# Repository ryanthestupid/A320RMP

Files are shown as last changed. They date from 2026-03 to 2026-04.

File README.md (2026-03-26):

# A320RMP
## A320 Radio Management Panel
_Made for MSFS2020, MobiFlight, RP2040, and the FlyByWire A32NX_

### What is this?
The A320RMP is a small desktop radio management panel for use with Microsoft Flight Simulator and MobiFlight, and is based off the Raspberry Pi RP2040 platform.

### Why was this made?
While flying on VATSIM with MSFS2020, I realized it was very difficult to switch frequencies through the mouse and scroll wheel in the FlyByWire A32NX. So, here is my version of the A320 RMP.

## Firmware
This RMP uses [MobiFlight](https://mobiflight.com) for its firmware and programming with a RP2040.<br>
MobiFlight Firmware and Project Files are in `mobiflight/` (`mfmc` and `mfproj`)<br>
**NOTE: RP2350/Pi Pico 2 will NOT work with MobiFlight. Only the RP2040 or Pi Pico 1 is compatible.**

## Links
Project Website (WIP) - https://ko6lvm.org/projects/a320rmp<br>
Hack Club Stasis Project - https://stasis.hackclub.com/dashboard/discover/cmmssstp8007o01myxmtd4il3

## Pictures
### Project Image
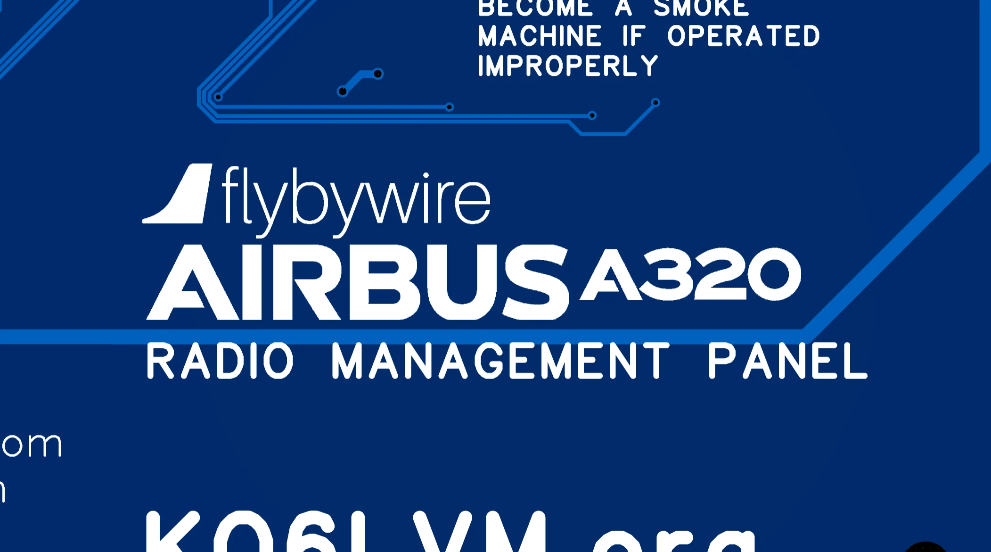
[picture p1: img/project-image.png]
Project Image
<br>
### Schematic
`img/schematic.png`<br>Schematic
### PCB
`img/pcb.png` - `pcb/A320RMPv1FinalGerber.zip`<br>PCB
### CAD / Models
#### Knob
`img/knob.png` - `cad/knob.step`<br>Knob<br>
#### Case
`img/case.png` - `cad/case.step`<br>Case<br>
#### Lid
`img/lid.png` - `cad/lid.step`<br>Lid<br>
#### Buttons
`img/button.png` - `cad/button.step`<br>Button<br>
### Final Render
`img/final1.png`<br>Final 1<br>
`img/final2.png`<br>Final 2<br>
`img/final3.png`<br>Final 3<br>

## BoM (General)
_Stasis BoM_ (`bom-stasis.csv`) _includes shipping, tax, fees, and required tools._<br>
_Below: General BoM_ (`bom-general.csv`)
| Name | Purpose | Quantity | Total Cost (USD) | Link | Distributor |
| :--- | :--- | :--- | :--- | :--- | :--- |
| Waveshare RP2040+ | Pico USB-C | 1 | 14.99 | [Link](https://www.amazon.com/RP2040-Plus-High-Performance-Microcontroller-Compatible-Pre-soldered/dp/B09KZFJTV9) | Amazon |
| SMD Stencil | Soldering | 1 | 7.11 | [Link](https://jlcpcb.com) | JLCPCB |
| PCB | 5 minimum | 5 | 9.00 | [Link](https://jlcpcb.com) | JLCPCB |
| Flux 30g | Paste | 1 | 9.99 | [Link](https://www.amazon.com/gp/product/B0D3H8NZLP) | Amazon |
| Solder Paste 30g | Sn63/Pb37 | 1 | 12.99 | [Link](https://www.amazon.com/gp/product/B0BH4HRWGX) | Amazon |
| Female Header Pins | Header C7499336 | 5 | 1.20 | [Link](https://www.lcsc.com/product-detail/C7499336.html) | LCSC |
| SPST Switch | Switch C1788492, THT | 2 | 1.26 | [Link](https://www.lcsc.com/product-detail/C1788492.html) | LCSC |
| Multiplexer IC | Multiplexer C6525 | 2 | 1.42 | [Link](https://www.lcsc.com/product-detail/C6525.html) | LCSC |
| 7seg CT IC | 7seg Controller IC C6705351 | 4 | 6.28 | [Link](https://www.lcsc.com/product-detail/C6705351.html) | LCSC |
| Logic Level IC | TI Logic Lvl C155176, 3.3V to 5V | 2 | 0.66 | [Link](https://www.lcsc.com/product-detail/C155176.html) | LCSC |
| Green L0603 | LED C19273151, min 100 | 100 | 0.60 | [Link](https://www.lcsc.com/product-detail/C19273151.html) | LCSC |
| Rotary Encoder | Rot Enc C470754, THT | 3 | 6.24 | [Link](https://www.lcsc.com/product-detail/C470754.html) | LCSC |
| 22Kohm R0603 | Resistor C2907015, min 100 | 100 | 0.10 | [Link](https://www.lcsc.com/product-detail/C2907015.html) | LCSC |
| 220ohm R0603 | Resistor C22962, min 100 | 100 | 0.13 | [Link](https://www.lcsc.com/product-detail/C22962.html) | LCSC |
| 6digit 7segment Display | Display C47471 | 3 | 5.20 | [Link](https://www.lcsc.com/product-detail/C47471.html) | LCSC |
| 6x6mm Button | Button C49234152, min 20 | 20 | 0.61 | [Link](https://www.lcsc.com/product-detail/C49234152.html) | LCSC |
| 10uF C0603 | Capacitor C1591, min 20 | 20 | 0.35 | [Link](https://www.lcsc.com/product-detail/C96446.html) | LCSC |
| 0.1uF C0603 | Capacitor C1591, min 100 | 100 | 0.28 | [Link](https://www.lcsc.com/product-detail/C1591.html) | LCSC |
_plus Applicable Tax, Fees, Shipping, and Tools_

## A320RMP wouldn't be possible without:
* VATSIM, https://vatsim.net
* MobiFlight, https://mobiflight.com
* FlyByWire Simulations, https://flybywiresim.com
* Hack Club, https://hackclub.com
* Stasis, https://stasis.hackclub.com

### A shoutout to:
* Oakland vARTCC, https://oakartcc.org

### And most importantly,
* @witherman3000, https://witherman3000.com

<br>Thanks for looking through my project!<br>
`5NN TNX FER QSO DE KO6LVM SK CL`

https://KO6LVM.org

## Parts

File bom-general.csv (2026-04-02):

Name | Purpose | Quantity | Total Cost (USD) | Link | Distributor
Waveshare RP2040+ | Pico USB-C | 1 | 14.99 | https://www.amazon.com/RP2040-Plus-High-Performance-Microcontroller-Compatible-Pre-soldered/dp/B09KZFJTV9 | Amazon
SMD Stencil | Soldering | 1 | 7.11 | https://jlcpcb.com | JLCPCB
PCB | 5 minimum | 5 | 9.00 | https://jlcpcb.com | JLCPCB
Flux 30g | Paste | 1 | 9.99 | https://www.amazon.com/gp/product/B0D3H8NZLP | Amazon
Solder Paste 30g | Sn63/Pb37 | 1 | 12.99 | https://www.amazon.com/gp/product/B0BH4HRWGX | Amazon
Female Header Pins | Header C7499336 | 5 | 1.20 | https://www.lcsc.com/product-detail/C7499336.html | LCSC
SPST Switch | Switch C1788492, THT | 2 | 1.26 | https://www.lcsc.com/product-detail/C1788492.html | LCSC
Multiplexer IC | Multiplexer C6525 | 2 | 1.42 | https://www.lcsc.com/product-detail/C6525.html | LCSC
7seg CT IC | 7seg Controller IC C6705351 | 4 | 6.28 | https://www.lcsc.com/product-detail/C6705351.html | LCSC
Logic Level IC | TI Logic Lvl C155176, 3.3V to 5V | 2 | 0.66 | https://www.lcsc.com/product-detail/C155176.html | LCSC
Green L0603 | LED C19273151, min 100 | 100 | 0.60 | https://www.lcsc.com/product-detail/C19273151.html | LCSC
Rotary Encoder | Rot Enc C470754, THT | 3 | 6.24 | https://www.lcsc.com/product-detail/C470754.html | LCSC
22Kohm R0603 | Resistor C2907015, min 100 | 100 | 0.10 | https://www.lcsc.com/product-detail/C2907015.html | LCSC
220ohm R0603 | Resistor C22962, min 100 | 100 | 0.13 | https://www.lcsc.com/product-detail/C22962.html | LCSC
6digit 7segment Display | Display C47471 | 3 | 5.20 | https://www.lcsc.com/product-detail/C47471.html | LCSC
6x6mm Button | Button C49234152, min 20 | 20 | 0.61 | https://www.lcsc.com/product-detail/C49234152.html | LCSC
10uF C0603 | Capacitor C96446, min 20 | 20 | 0.35 | https://www.lcsc.com/product-detail/C96446.html | LCSC
0.1uF C0603 | Capacitor C1591, min 100 | 100 | 0.28 | https://www.lcsc.com/product-detail/C1591.html | LCSC

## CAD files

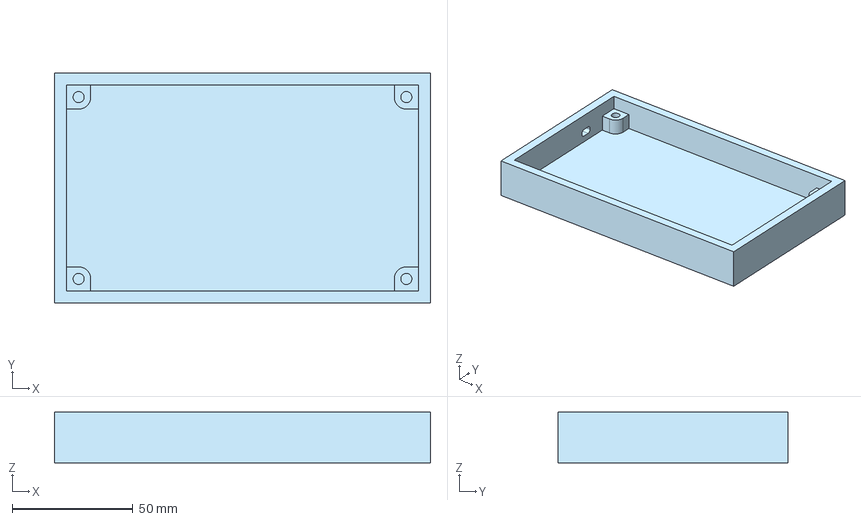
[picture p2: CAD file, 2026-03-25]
A320RMPCase.step
155.7 x 95.3 x 21.0 mm

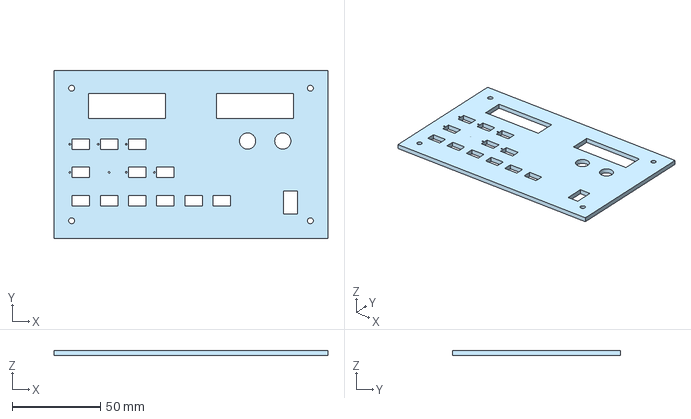
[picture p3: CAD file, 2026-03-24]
A320RMPLid.step
155.7 x 95.3 x 3.00 mm

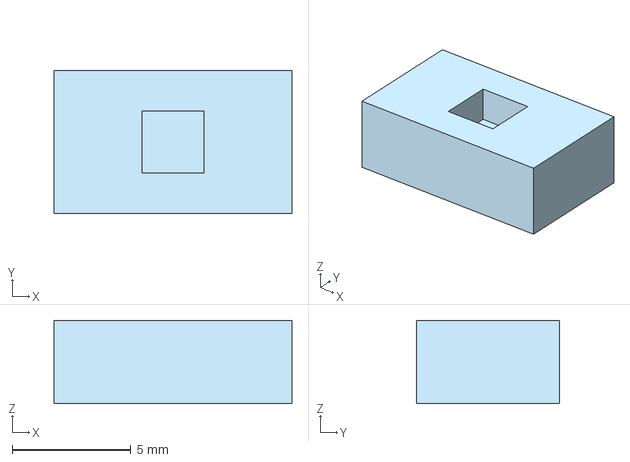
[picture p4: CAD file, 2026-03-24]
A320RMPButton.step
10.0 x 6.00 x 3.50 mm

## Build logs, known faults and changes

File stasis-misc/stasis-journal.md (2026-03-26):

<!--
  This journal is auto generated by Stasis.
-->

# 3/26/2026 2 AM - Everything Done!

_Time spent: 0.01666666666666667h_

1 min logged as I need to log *some* time for the journal.

Everything has been completed, as per the *Submission Guidelines*.



Checklist
* Originality - yes, this is my project.
* Shipped and complete:
* CAD assembly with all electronics and parts - Yes
* Firmware present - yes (mobiflight)
* Sanity checked - yes
* 3D Render - "render"-ish, but yes.
* BOM in CSV - Generic and Stasis, yes.
* PCB source files - Gerber, yes.
* Any other files - Mobiflight config files, etc, yes.
* STEP files for CAD files, yes. (`cad/`)
* Readable and organized into folders, yes.

Readme:
* Description - yes
* Sentences on why - yes
* Pictures - plenty, yes
* Screenshot with full model - yes
* PCB screenshot - yes
* Wiring diagrams - yes (schematic)
* BoM in table format - yes






# 3/25/2026 7 AM - README (In Stasis Copy)

_Time spent: 2h_

# Rest of completed Readme and BOM in Github
# A320RMP
## A320 Radio Management Panel
_Made for MSFS2020, MobiFlight, RP2040, and the FlyByWire A32NX_

### What is this?
The A320RMP is a small desktop radio management panel for use with Microsoft Flight Simulator and MobiFlight, and is based off the Raspberry Pi RP2040 platform.

### Why was this made?
While flying on VATSIM with MSFS2020, I realized it was very difficult to switch frequencies through the mouse and scroll wheel in the FlyByWire A32NX. So, here is my version of the A320 RMP.

## Pictures
### Schematic
`img/schematic.png`
A320RMPv1Schematic
https://stasis.hackclub-assets.com/images/1774469948065-c5vn6g.png
### PCB Only
`img/pcb.png`
A320RMPv1PCB2DTop
https://stasis.hackclub-assets.com/images/1774470086891-i2ej90.png
### CAD / Models
#### Knob
`img/knob.png`
`cad/knob.step`

https://stasis.hackclub-assets.com/images/1774470168708-qcuh1a.png
#### Case

https://stasis.hackclub-assets.com/images/1774470365832-sbevvn.png
#### Lid

https://stasis.hackclub-assets.com/images/1774470316983-m36m6g.png
#### Buttons

https://stasis.hackclub-assets.com/images/1774470339608-9jjzfl.png
### Final Render




## BoM
WIP - Check Stasis

## A320RMP wouldn't be possible without:
* VATSIM, https://vatsim.net
* FlyByWire Simulations, https://flybywiresim.com
* Oakland vARTCC, https://oakartcc.org
* Hack Club, https://hackclub.com
* Stasis, https://stasis.hackclub,com
### And most importantly,
* @witherman3000, https://witherman3000.com

Thanks for looking through my project!
`5NN THX FER RPRT DE KO6LVM SK CL`











# 3/25/2026 4 AM - Github, Readme, and Knob

_Time spent: 1.5h_

## Knob
Knob - made in Onshape, from encoder specs from LCSC


## Github
Uploaded:
* PCB STEP
* PCB Gerber
* Case STEP
* Lid STEP
* Button STEP
* Knob STEP
* Mobiflight MFMC
* Mobiflight MFPROJ
* https://github.com/ko6lvm/A320RMP

## README
WIP - on local disk. Will be uploaded ~26-27th.
Screenshot 2026-03-25 at 12.11.35 AM




# 3/25/2026 2 AM - MobiFlight Firmware

_Time spent: 2h_

* Firmware and project file uploaded to Github
* HF1/HF2/SEL/AM LEDs not configured due to those variables not present in A32NX MobiFlight presets
* Everything else programmed into MobiFlight
* Rotary encoder button as of now does not do anything











# 3/24/2026 9 PM - MobiFlight Pins

_Time spent: 2h_

## Multiplexer
### Data
| Name | IC Pin | Pico GP |
|---|---|---|
| S0 | 10 | GP0 |
| S1 | 11 | GP1 |
| S2 | 14 | GP2 |
| S3 | 13 | GP3 |
| C I/O | 1 | GP4 |
### Buttons
| Name | IC Pin |
|-----|-----|
| SW(N) | L(N) |
| i.e. S2 | L2 |

## Rotary Encoders
### SW13 (Left, MHz)
| Name | Pico GP | Purpose |
|-----|-----|-----|
| A | GP5 | Left |
| B | GP6 | Right |
| E | GP7 | Button |

### SW14 (Right, KHz)
| Name | Pico GP | Purpose |
|-----|-----|-----|
| A | GP8 | Left |
| B | GP9 | Right |
| E | GP10 | Button |

## LEDs
| Name | Pico GP | Purpose |
|-----|-----|-----|
| U3 | GP14 | VHF1 |
| U4 | GP15 | VHF2 |
| U5 | GP16 | VHF3 |
| U6 | GP17 | HF1 |
| U7 | GP18 | HF2 |
| U8 | GP19 | SEL |
| U9 | GP20 | AM |

## 7 Segments
_Uses MAX7219, 6 digits each._
_Data cascaded into U11 from U13 DOUT, only U13 recieves DIN from Pico/MobiFlight. All data is ran through Logic Level Shifter (Shifter pins used in place of MAX7219 pins)_
### U11-LED2 and U13-LED3
_UA in Name states Both U11 and U13_
| Name | Pico GP | Purpose |
|-----|-----|-----|
| U13 DIN | GP27_A2 | Data In |
| UA LOAD | GP22 | Load All |
| UA CLOCK | GP21 | Clock | 

## SPST On/Off
| Name | Pico GP |
|-----|-----|
| U15 | GP11 |

## Reference
_For the MAX7129 pins use the logic level shifter in pins instead_





## Mobiflight configs are on Github.




# 3/24/2026 3 AM - CAD

_Time spent: 3h_

## Lid



* 1mm OD circles for LEDs
* 16mm vert and horz spacing for buttons and LEDs
* Everything else done to PCB spec
* 5mm border

## Button



* 2.6mm button press-fit
* 6*10mm Button

## Case

* 4mm Bottom Spacing
* 9mm Top Spacing

## PCB
* DRC final run
* Silkscreen final
* Copper pour final rebuild
* Sanity checked

## Github Uploaded:
* Final PCB Gerber file ZIP
* Button STEP
* Lid STEP
* Case STEP
* PCB EasyEDA Pro STEP Export





# 3/22/2026 11 PM - CAD and Case

_Time spent: 1.25h_

## Dimensions
155.67mm * 95.3mm
(5mm wall)

* 7seg height: 9mm
* Pi Pico USB-C Clone w/ Headers: 4mm
* Female Headers: 4mm
* "Standoff" case height: 8.5mm
* Heat set insert OD: 5mm
* Heat set insert 3d print hole: 4.6mm
* All other components dimensions in their Datasheets


i.e. In this case, construction dual-point rect at 129.413x69.83mm and then a center-point-rect at its footprint

## Sanity checked!
## Case worked on
### Check Hackatime




# 3/22/2026 7 AM - PCB

_Time spent: 1h_

## PCB
* 2-layer design now
* 1mm power traces (yes, I don't need this much but it's fine)
* Made it 2-layer for cheaper JLCPCB costs
Screenshot 2026-03-22 at 12.30.13 AM

Screenshot 2026-03-22 at 12.30.29 AM




# 3/21/2026 1 AM - PCB

_Time spent: 2.5h_

## PCB
* Copper Pour for GND
* GND nets on Pico
* Component Data Routing
## BoM
* Stasis BoM populated with LCSC and Amazon parts
* JLCPCB will be added after quote








# 3/20/2026 3 AM - Parts Assignment

_Time spent: 0.75h_

# Parts BOM
## LCSC
* C = Capacitor
* R = Resistor
* L = LED
* B = Button
* IC = IC/Chip

_Note: Any item's quantity that's unreasonably high (i.e. 100 capacitors) is due to the minimum purchase count in LCSC. However, these are so cheap that 100 vs 4 won't really make a difference, as it is the matter of cents._
| Part | LCSC P# | Qty | Cost (Per)| Total |
|---|---|---|---|---|
| 0.1uF C0603 | C1591 | 100 | $0.0028 | $0.28 |
| 10uF C0603 | C96446 | 20 | $0.0176 | $0.35 |
| 6x6 B | C49234152 | 20 | $0.0306 | $0.58 |
| 6d7s L | C47471 | 3 | $1.7325 | $5.20 |
| 220 R | C22962 | 100 | $0.0013 | $0.13 |
| 22K R | C2907015 | 100 | $0.001 | $0.11 |
| Rot Enc | C470754 | 3 | $2.08 | $6.23 |
| Green L | C19273151 | 100 | $0.006 | $0.60 |
| Log Lvl IC | C155176 | 2 | $0.3292 | $0.66 |
| 7seg CT IC | C6705351 | 4 | $1.5703 | $6.28 |
| Multiplexer IC | C6525 | 2 | $0.7064 | $1.41 |
| SPST | C1788492 | 2 | $0.6153 | $1.23 |
| Header Pin F | C7499336 | 4 | $0.24 |

## Other Parts
* Looking at TI CD74HC4067PWR
* Switch to TI CD4067BM96, LCSC C6525
* * Do this in schematic/pcb.
## Some part photos








# 3/20/2026 2 AM - PCB

_Time spent: 2.5h_

## PCB
* MAX7129 routing completed
* 0.1uF and 10uF capacitors added in parallel from VBUS to GND next to the multiplexer
* Main power traces (0.7mm) done
* Main power vias (0.7mm OD 0.4mm ID) done
* Basic naming and silkscreening done
## TO DO
* Wire Pi to other Components
* Sanity-check with others (schematic and PCB)
* Ground net, pour, or traces
## Pictures
### Power Traces (Inner1 Layer)

### Bottom Layer

### Top Layer

### Render

### Render without Parts










# 3/19/2026 4 PM - PCB

_Time spent: 1.25h_

## PCB
* 1x MAX7219 routed to 6dig7seg
* Logic Level Shifter 1/2 outputs complete
* Multiplexer inputs complete
* Basic silkscreens
* Capacitor Placement
* Pi Placement








# 3/19/2026 6 AM - PCB and Schematic

_Time spent: 6h_

~6 hours over the course of the day

Completed:

## Schematic
* Completed
* All ICs now SMD (no THT)
* Not fully sanity-checked
* 2x MAX7219s, 1x Multiplexer, 1x Logic Level Shifter, 2x 6-digit 7-segment displays, 13x buttons, 7x LEDs, 1x SPST switch, 2x rotary encoders

## PCB
* Initial Layout
* Routing Required
* * Routing done for: Some small resistors and capacitors
* * Routing semi-done for: Buttons and Multiplexer; must move back-mounted resistors back onto the front
* * Rest must be started / done.
* 4-Layer
* EasyEDA Pro








# 3/18/2026 3 AM - PCB

_Time spent: 4h_

OVER THE COURSE OF THE SCHOOL DAY WHEN I HAVE TIME IN CLASS...
## PCB
* Complete (not checked yet)
* 4 layer PCB



## Schematic
* Complete (not checked yet)




# 3/17/2026 1 AM - Rotary Encoders and Switch

_Time spent: 0.2333333333333333h_

START 6:23 PM PDT END 6:37 PM PDT
## Rotary Encoder
* ALPSALPINE EC11E15244B2
* https://www.lcsc.com/product-image/C470754.html
* Has push button, but is not used at the moment, but can be mapped.
* **SW13 / Left**
* * A - GP5 / P7 (A)
* * B - GP6 / P9 (B)
* * C - GND (Encoder GND)
* * D - GND (Button GND)
* * E - GP7 / P10 (Button)
* * 6 - GND
* * 7 - GND
* **SW14 / Right**
* * A - GP8 / P11 (A)
* * B - GP9 / P12 (B)
* * C - GND (Encoder GND)
* * D - GND (Button GND)
* * E - GP10 / P14 (Button)
* * 6 - GND
* * 7 - GND
## Switch
* As mentioned before, SPST
* GP11 / P15

## Images







# 3/17/2026 12 AM - SPST, Buttons Multiplexer

_Time spent: 1h_

START 4:50 PM PDT END 5:52 PM PDT
## SPST Switch
* YUEN FUNG MT-0-102-A101-M200-RS
* https://www.lcsc.com/product-detail/C1788492.html
* SPST, 125V Max, 5A Max
* THT
## Buttons
* Due to pin limit we are using a multiplexer.
* Multiplexer: TI CD74HC4067
* https://www.lcsc.com/product-detail/C1545936.html
* SW# Button - To L# on Multiplexer
* E# - Grounded
* S# on Multiplexer - GPIO # on Pico
* COMMON INPUT/OUTPUT Pin 1 on Multiplexer - GPIO 4 (6)








# 3/16/2026 11 PM - MAX7219 and Complete Schematic

_Time spent: 0.9666666666666667h_

START 3:25 PM PDT END 4:23 PM PDT
## Schematic has been completed, however I am having someone else sanity-check it.
## Logic Level Shifter
* A input, Y output
* 3.3V logic to 5V logic
* **Pins Used:**
* 1. VCC - to 5V VBAT
* 2. GND - to GND
* 3. #1OE - to GND to enable 1
* 4. #2OE - to GND to enable 2
* 5. #3OE - to GND to enable 3
* 6. 1A - to Pico GP21 (34) for CLOCK
* 7. 1Y - to Both 7219 "CLK" (13)
* 8. 2A - to Pico GP22 (32) for LOAD
* 9. 2Y - to Both 7219 "LOAD" (CS#) (12)
* 10. 3A - to Pico GP27_A2 (29) for DATA
* 11. 3Y - to U13 **ONLY** "DIN" (1)
## MAX7219
* Takes 5V
* Takes the following inputs:
* **Clock**
* i. Shared, "metronome"
* **Data**
* i. Actual data, goes into U13 "DIN" only
* ii. Pico -> Logic Shift -> U13 DIN -> U13 DOUT -> U11 DIN
* **Load**
* i. Shared, command to refresh or "commit" 

## Photos






# 3/16/2026 10 PM - 7 Segment, MAX7219, and Logic Level Shifter

_Time spent: 0.8h_

START 2:15 PM PDT END 3:03 PM PDT
## New Parts
* Logic Level Shifter - 3.3V to 5V - TI SN74AHCT125N - https://www.lcsc.com/product-detail/C354152.html
* 1. For MAX7219
* MAX7219 will pull VBUS 5V








# 3/16/2026 3 PM - Schematic and MobiFlight

_Time spent: 0.75h_

START 8:00 AM PDT END 8:50AM PDT
## Parts
* 2x 6-digit 7-segment display - ZHIHAO FJ3661AH - https://www.lcsc.com/product-detail/C47471.html
* 13x 4-pin Button - hanxia HX-6x6x7.3-TP FT - https://www.lcsc.com/product-detail/C49234152.html
* 2x MAS7219 - https://www.lcsc.com/product-detail/C492111.html
* 7x Green 0603 LED - YONGYUTAI YLED0603G - https://www.lcsc.com/product-detail/C19273151.html - LEDs only for top two rows of buttons








# 3/16/2026 6 AM - Basic Brainstorming

_Time spent: 1h_

START 10:35PM PDT END 11:35PM
## Stats / Info - A320 RMP
* Airbus A320 Radio Management Panel (Upper)
* https://docs.flybywiresim.com/pilots-corner/a32nx/a32nx-briefing/flight-deck/pedestal/rmp/
* 13 Buttons (12 Main + 1 A-B Switcher)
* 1. Mains: VHF1/2/3, HF1/2, AM, NAV, VOR, ILS, MLS, ADF, BFO
* ii. A-B Switch (Backlit)
* 1 SPST Switch
* 2 Rotary Encoders (Stacked)
* Two 6-digit 8-segment displays
* One "VHF 2/3 Selected" LED
* 12 LEDs Occompanying Main buttons
## Ideas
* RP2040 USB-C Clone
* i.e. https://www.aliexpress.us/item/3256806763219822.htm
## Photos
Screenshot 2026-03-15 at 11.33.37 PM
Screenshot 2026-03-15 at 11.35.12 PM
Screenshot 2026-03-15 at 11.35.29 PM





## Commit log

2026-03-24 Add lid and button
    [A320RMPButton.step, A320RMPLid.step]
2026-03-24 EasyEDA Pro Export for the PCB
2026-03-24 Case upload
    [A320RMPCase.step]
2026-03-25 Case with USB-C (4*6mm hole with fillet)
    [A320RMPCase.step]
2026-04-02 Fix capacitor entry in bom-general.csv
    [bom-general.csv]
